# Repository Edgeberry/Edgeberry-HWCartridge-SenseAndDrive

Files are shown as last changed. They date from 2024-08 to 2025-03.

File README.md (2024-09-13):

Edgeberry banner

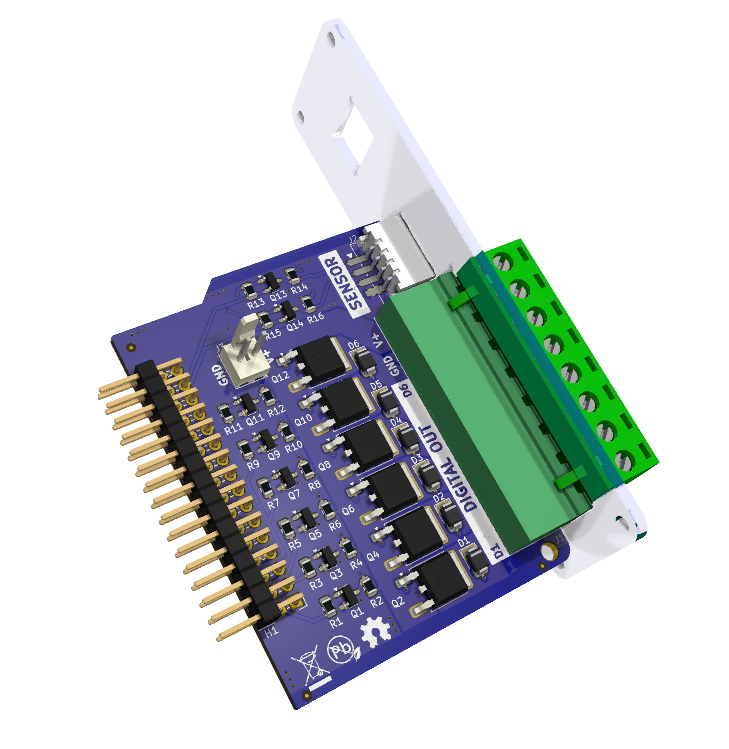
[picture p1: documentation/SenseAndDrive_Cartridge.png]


The Edgeberry **Sense'n'Drive Hardware Cartridge** expands your project's capabilities with 6 digital outputs and an I²C sensor port.

The Raspberry Pi's I²C bus is levelshifted to 5V, enabling compatibility with a wide range of peripheral components. The bus is routed to a 4P-2.0mm D90 connector, compatible with the Grove standard.

The digital outputs are P-channel MOSFETs configured for sourcing. An external power source can be applied to drive the digital outputs, or the base board's power source can be used by internally wiring the dedicated connectors.

<br clear="right"/>

## Usage
### I²C
Enable the I²C port using `raspi-config`:
```
$ sudo raspi-config
> 3     Interface options
> I5    I2C
> Enable
```
Now you can use the I²C interface `/dev/i2c-1` for connecting peripheral components.

### Digital Outputs
The digital outputs are connected as following:
|  GPIO  | OUTPUT |
|---|---|
| GPIO21 | D1 |
| GPIO20 | D2 |
| GPIO16 | D3 |
| GPIO13 | D4 |
| GPIO12 | D5 |
| GPIO18 | D6 |

Controling the digital outputs can be done from the commandline using `pinctrl`.
```
pinctrl set 21 op dh
```
**'op' meaning 'output', 'dh' digital high, 'dl' digital low.*

## License & Collaboration
**Copyright© 2024 Sanne 'SpuQ' Santens**. This project is released under the **CERN OHL-W** license. The [Rules & Guidelines](https://github.com/Edgeberry/.github/blob/main/brand/Edgeberry_Trademark_Rules_and_Guidelines.md) apply to the usage of the Edgeberry™ brand.

### Collaboration

If you'd like to contribute to this project, please follow these guidelines:
1. Fork the repository and create your branch from `main`.
2. Make your changes and ensure they adhere to the project's design style and conventions.
3. Test your changes thoroughly.
4. Ensure your commits are descriptive and well-documented.
5. Open a pull request, describing the changes you've made and the problem or feature they address.

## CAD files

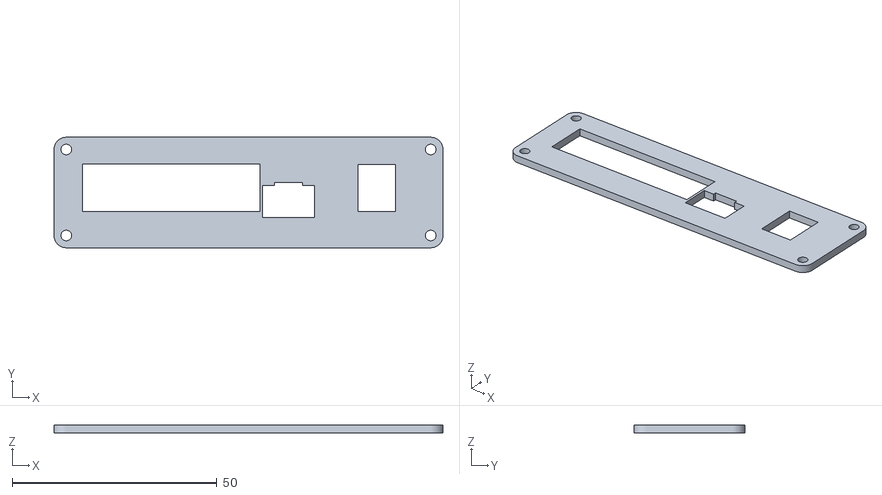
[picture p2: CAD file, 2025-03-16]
documentation/Edgeberry_SenseAndDrive_faceplate.stl
95.0 x 27.0 x 2.00

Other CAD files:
Edgeberry_SenseAndDrive_faceplate.FCStd

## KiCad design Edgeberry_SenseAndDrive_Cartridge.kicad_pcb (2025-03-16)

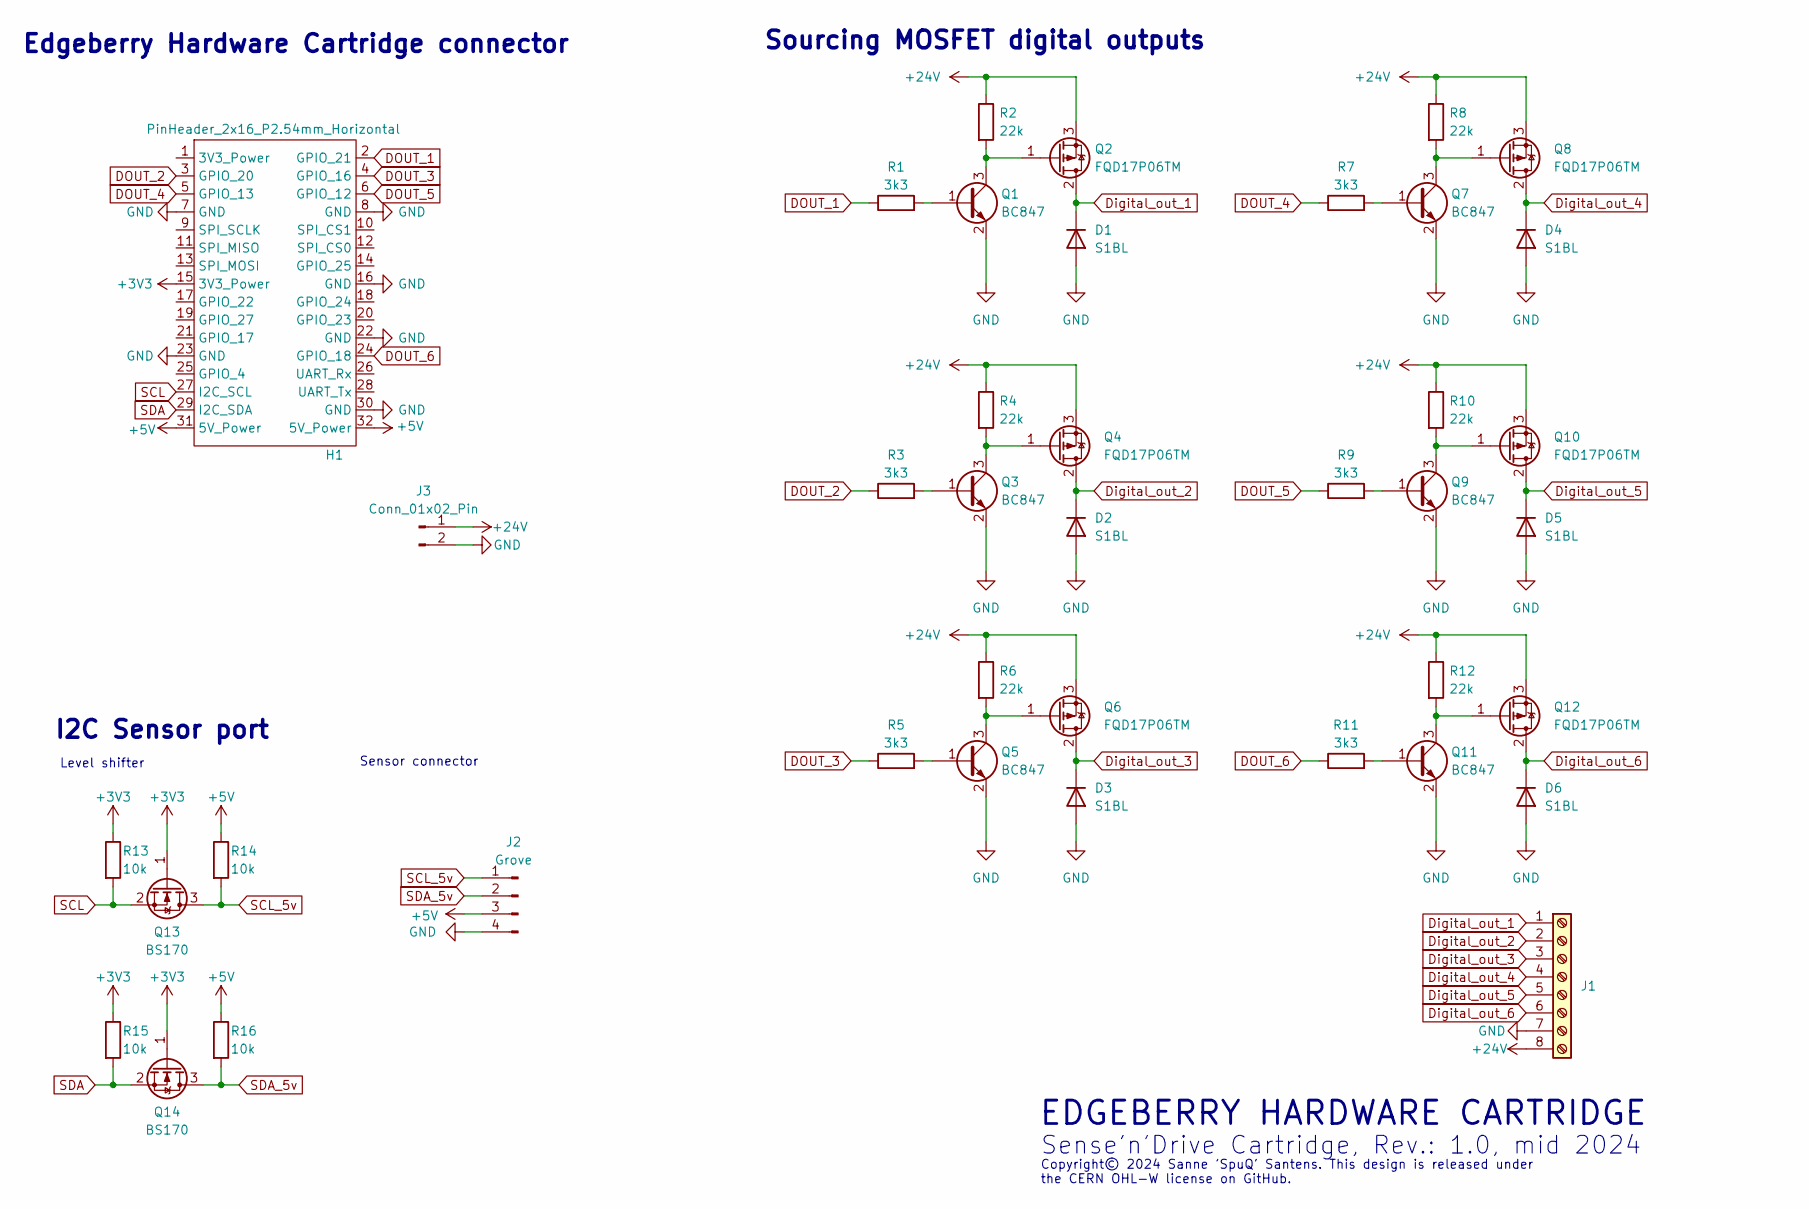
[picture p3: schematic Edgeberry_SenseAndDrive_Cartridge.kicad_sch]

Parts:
D1, D2, D3, D4, D5, D6: S1BL; S1BL_diode
H1: PinHeader_2x16_P2.54mm_Horizontal
J1: Screw_Terminal_01x08; PhoenixContact_MSTBA_2,5_8-G-5,08_1x08_P5.08mm_Horizontal
J2: Grove; Grove_SMD_right_angle
J3: Conn_01x02_Pin; Molex_KK-254_AE-6410-02A_1x02_P2.54mm_Vertical
Q1, Q3, Q5, Q7, Q9, Q11: BC847; SOT-23
Q2, Q4, Q6, Q8, Q10, Q12: FQD17P06TM; TO-252-2
Q13, Q14: BS170; SOT-23
R1, R3, R5, R7, R9, R11: 3k3; R_0805_2012Metric
R2, R4, R6, R8, R10, R12: 22k; R_0805_2012Metric
R13, R14, R15, R16: 10k; R_0805_2012Metric

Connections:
+3V3: H1.15 (3V3_Power), Q13.1 (G), Q14.1 (G), R13.1, R15.1
+5V: H1.31 (5V_Power), H1.32 (5V_Power), J2.3, R14.1, R16.1
+24V: J1.8, J3.1, Q2.3 (S), Q4.3 (S), Q6.3 (S), Q8.3 (S), Q10.3 (S), Q12.3 (S), R2.1, R4.1, R6.1, R8.1, R10.1, R12.1
DOUT_1: H1.2 (GPIO_21), R1.1
DOUT_2: H1.3 (GPIO_20), R3.1
DOUT_3: H1.4 (GPIO_16), R5.1
DOUT_4: H1.5 (GPIO_13), R7.1
DOUT_5: H1.6 (GPIO_12), R9.1
DOUT_6: H1.24 (GPIO_18), R11.1
Digital_out_1: D1.1 (K), J1.1, Q2.2 (D)
Digital_out_2: D2.1 (K), J1.2, Q4.2 (D)
Digital_out_3: D3.1 (K), J1.3, Q6.2 (D)
Digital_out_4: D4.1 (K), J1.4, Q8.2 (D)
Digital_out_5: D5.1 (K), J1.5, Q10.2 (D)
Digital_out_6: D6.1 (K), J1.6, Q12.2 (D)
GND: D1.2 (A), D2.2 (A), D3.2 (A), D4.2 (A), D5.2 (A), D6.2 (A), H1.7 (GND), H1.8 (GND), H1.16 (GND), H1.22 (GND), H1.23 (GND), H1.30 (GND), J1.7, J2.4, J3.2, Q1.2 (E), Q3.2 (E), Q5.2 (E), Q7.2 (E), Q9.2 (E), Q11.2 (E)
unnamed: Q1.1 (B), R1.2
unnamed: Q1.3 (C), Q2.1 (G), R2.2
unnamed: Q3.1 (B), R3.2
unnamed: Q3.3 (C), Q4.1 (G), R4.2
unnamed: Q5.1 (B), R5.2
unnamed: Q5.3 (C), Q6.1 (G), R6.2
unnamed: Q7.1 (B), R7.2
unnamed: Q7.3 (C), Q8.1 (G), R8.2
unnamed: Q9.1 (B), R9.2
unnamed: Q9.3 (C), Q10.1 (G), R10.2
unnamed: Q11.1 (B), R11.2
unnamed: Q11.3 (C), Q12.1 (G), R12.2
SCL: H1.27 (I2C_SCL), Q13.2 (S), R13.2
SCL_5v: J2.1, Q13.3 (D), R14.2
SDA: H1.29 (I2C_SDA), Q14.2 (S), R15.2
SDA_5v: J2.2, Q14.3 (D), R16.2

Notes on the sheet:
Copyright© 2024 Sanne 'SpuQ' Santens. This design is released under the CERN OHL-W license on GitHub.
I2C Sensor port
EDGEBERRY HARDWARE CARTRIDGE
Sense'n'Drive Cartridge, Rev.: 1.0, mid 2024
Sourcing MOSFET digital outputs
Sensor connector
Level shifter
Edgeberry Hardware Cartridge connector

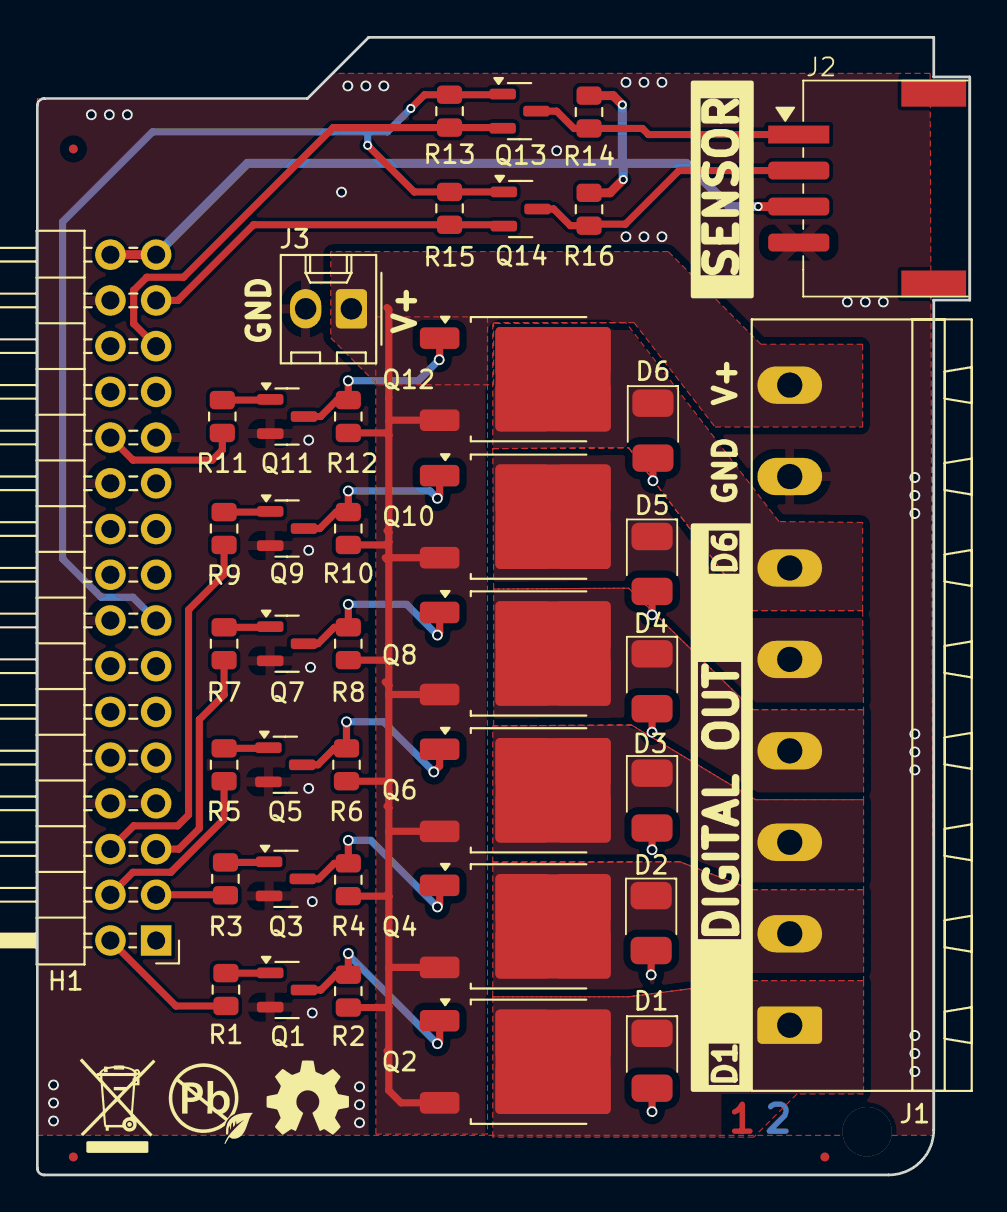
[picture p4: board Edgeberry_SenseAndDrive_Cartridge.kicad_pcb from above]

Board: 2 copper layers, 51.8 x 63.2 mm, 40 parts (0 on the bottom side), 32 nets.

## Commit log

2024-08-24 First version
    [Edgeberry_SenseAndDrive_Cartridge.kicad_pcb, Edgeberry_SenseAndDrive_Cartridge.kicad_sch]
2024-08-25 Update resistor values
    [Edgeberry_SenseAndDrive_Cartridge.kicad_sch]
2024-08-28 Cartridge faceplate
    [Edgeberry_SenseAndDrive_faceplate.FCStd]
2024-09-22 ReadMe: Tindie button
2024-11-01 Faceplate: power jack cutout
    [Edgeberry_SenseAndDrive_faceplate.FCStd]
2024-12-08 Version 1.0 cleanup
    [Edgeberry_SenseAndDrive_Cartridge.kicad_pcb, Edgeberry_SenseAndDrive_Cartridge.kicad_sch, Edgeberry_SenseAndDrive_faceplate.FCStd]
